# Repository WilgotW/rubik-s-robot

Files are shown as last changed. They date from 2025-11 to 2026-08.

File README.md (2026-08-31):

*Rubiks Cube Robot*

The purpose of this robot is to be able to scan, calculate solution and solve a rubiks cube. The robot has several different parts that interconnect: 
Mechanical (Robot Arm, color sensor, servos), 
Electronics (Custom made PCB with a STM32 chip), 
programming (Both computer program for solving the Rubiks cube as well as C programming for the STM32 IC)

This projects has divided all the files into sorted folders for each part of the robot told above. 

**Images**





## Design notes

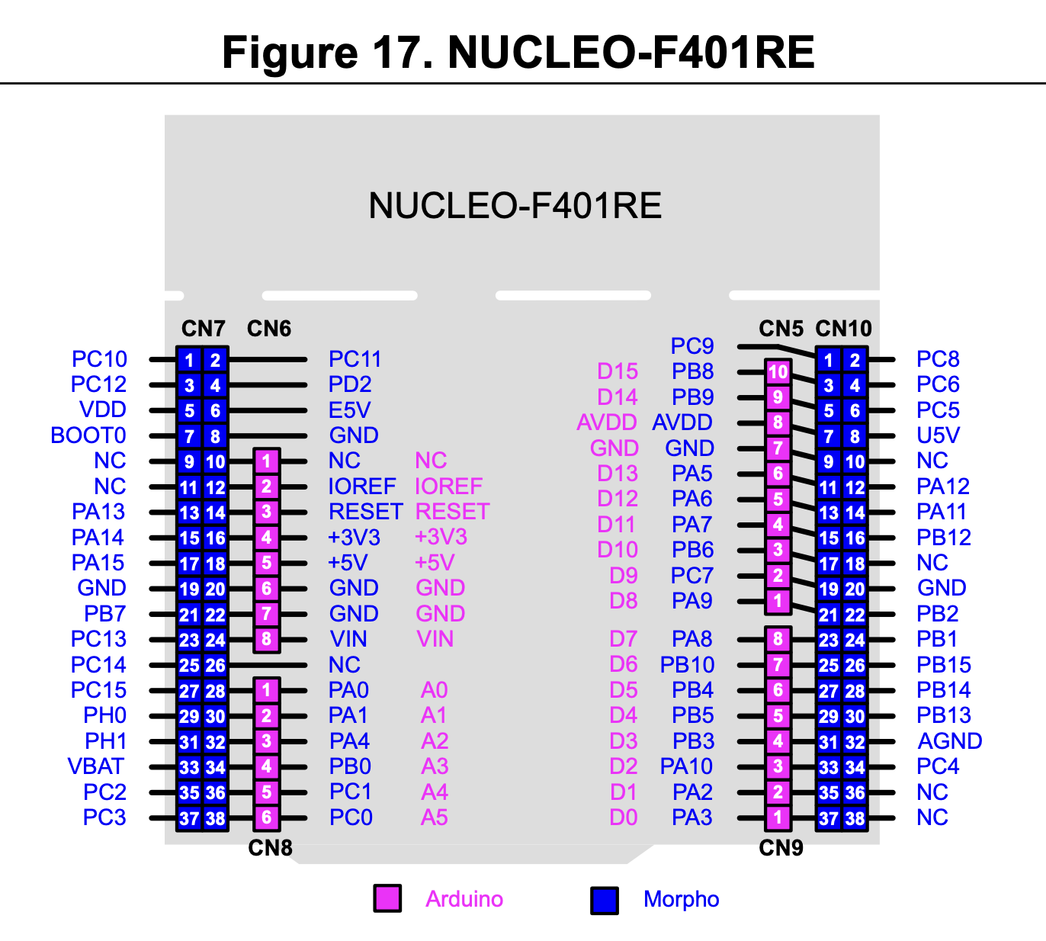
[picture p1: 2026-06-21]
rubiks-code/images/pin-layout.png

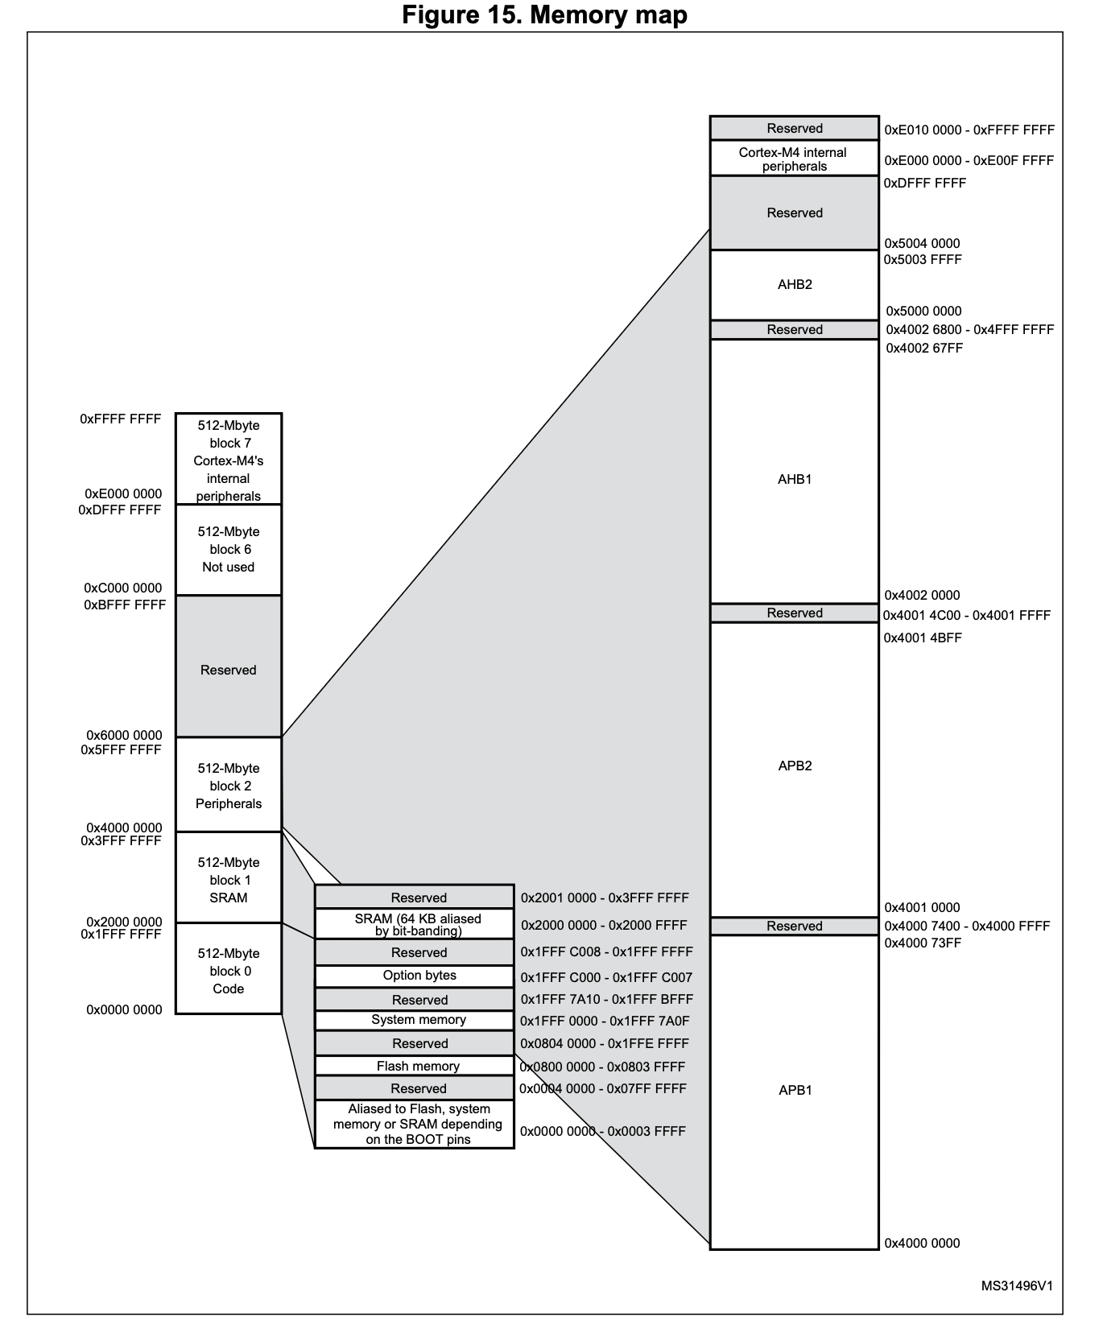
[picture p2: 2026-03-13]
rubiks-bare-metal/docs/memory_map.png

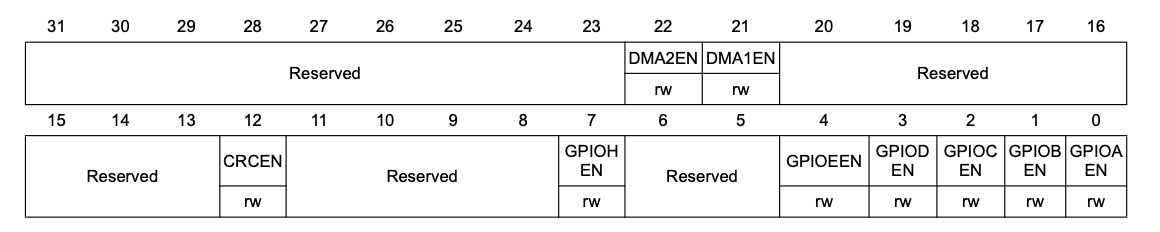
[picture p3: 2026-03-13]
rubiks-bare-metal/docs/RCC_AHB1ENR.png

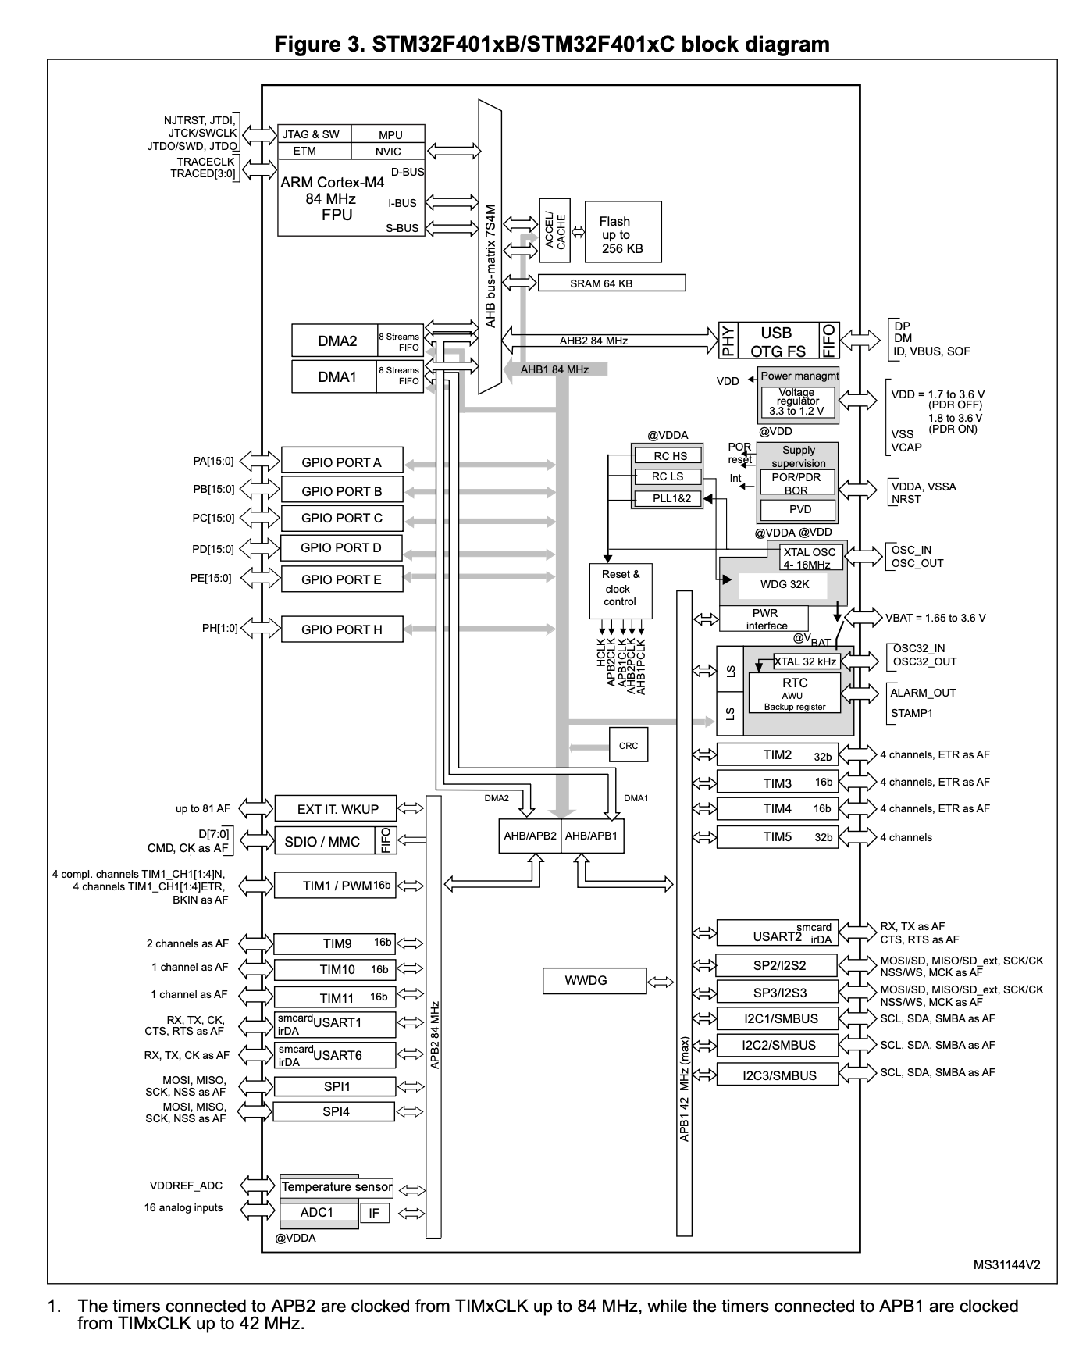
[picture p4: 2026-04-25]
rubiks-bare-metal/docs/Block_diagram.png

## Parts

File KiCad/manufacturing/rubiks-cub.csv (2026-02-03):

Reference | Qty | Value | DNP | Exclude from BOM | Exclude from Board | Footprint | Datasheet
A1,A2 | 2 | Pololu_Breakout_A4988 |  |  |  | Module:Pololu_Breakout-16_15.2x20.3mm | https://www.pololu.com/product/2980/pictures
C1,C2,C3,C4,C9,C16 | 6 | 100n |  |  |  | Capacitor_SMD:C_0402_1005Metric | ~
C5 | 1 | 10u |  |  |  | Capacitor_SMD:C_0603_1608Metric | ~
C6 | 1 | 10n |  |  |  | Capacitor_SMD:C_0402_1005Metric | ~
C7,C8 | 2 | 1u |  |  |  | Capacitor_SMD:C_0402_1005Metric | ~
C10,C11 | 2 | 10p |  |  |  | Capacitor_SMD:C_0402_1005Metric | ~
C12,C13 | 2 | 22u |  |  |  | Capacitor_SMD:C_0805_2012Metric | ~
C14 | 1 | 470u |  |  |  | Capacitor_THT:C_Radial_D8.0mm_H7.0mm_P3.50mm | ~
C15,C18 | 2 | 100u |  |  |  | Capacitor_THT:C_Radial_D8.0mm_H7.0mm_P3.50mm | ~
C17 | 1 | 4.7u |  |  |  | Capacitor_SMD:C_0603_1608Metric | ~
D1 | 1 | RED |  |  |  | LED_SMD:LED_0603_1608Metric | ~
D2 | 1 | SS34 |  |  |  | Diode_SMD:D_SMA | https://www.vishay.com/docs/88751/ss32.pdf
FB1 | 1 | 120R |  |  |  | Inductor_SMD:L_0603_1608Metric | ~
H1,H2,H3,H4 | 4 | MountingHole |  | Excluded from BOM |  | MountingHole:MountingHole_2.2mm_M2 | ~
J1 | 1 | USB_B_Mini |  |  |  | Connector_USB:USB_Mini-B_Wuerth_65100516121_Horizontal | ~
J2,J3,J4,J9,J16 | 5 | Conn_01x04_Pin |  |  |  | Connector_PinHeader_1.00mm:PinHeader_1x04_P1.00mm_Vertical | ~
J5 | 1 | Jack-DC |  |  |  | Connector_BarrelJack:BarrelJack_Horizontal | ~
J6,J13,J14,J15 | 4 | Conn_01x01_Pin |  |  |  | Connector_PinHeader_2.54mm:PinHeader_1x01_P2.54mm_Vertical | ~
J12 | 1 | Conn_01x03_Pin |  |  |  | Connector_PinHeader_1.00mm:PinHeader_1x03_P1.00mm_Vertical | ~
R1 | 1 | 10k |  |  |  | Resistor_SMD:R_0402_1005Metric | ~
R2,R3,R4,R6 | 4 | 1k5 |  |  |  | Resistor_SMD:R_0402_1005Metric | ~
SW1 | 1 | SW_SPDT |  |  |  | Button_Switch_SMD:SW_SPDT_PCM12 | ~
SW2 | 1 | SW_Push |  |  |  | Button_Switch_THT:SW_PUSH_6mm | ~
U1 | 1 | STM32F401RETx |  |  |  | Package_QFP:LQFP-64_10x10mm_P0.5mm | https://www.st.com/resource/en/datasheet/stm32f401re.pdf
U2 | 1 | AMS1117-3.3 |  |  |  | Package_TO_SOT_SMD:SOT-223-3_TabPin2 | http://www.advanced-monolithic.com/pdf/ds1117.pdf
Y1 | 1 | 16MHz |  |  |  | Crystal:Crystal_SMD_3225-4Pin_3.2x2.5mm | ~

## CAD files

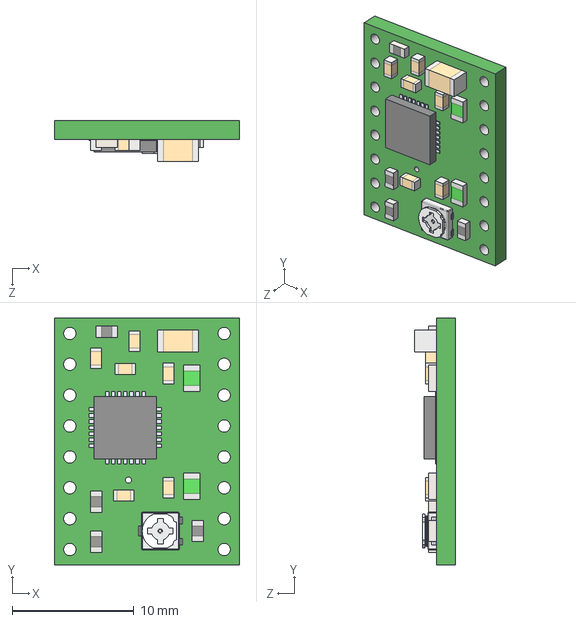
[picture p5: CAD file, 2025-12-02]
KiCad/models/a4988-stepper-motor-driver-carrier.step
15.2 x 20.3 x 3.37 mm

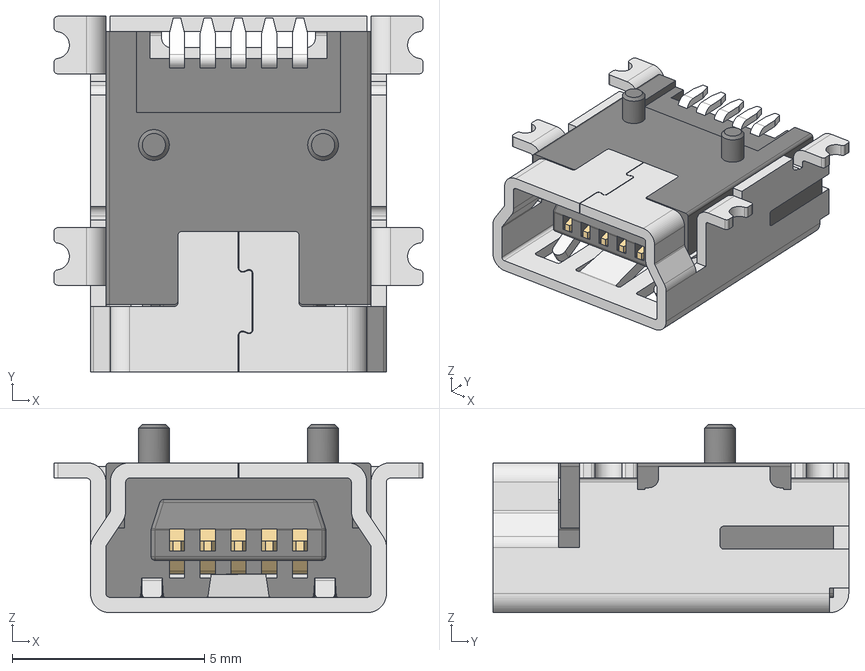
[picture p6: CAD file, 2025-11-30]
KiCad/models/65100516121+(rev1).stp
9.60 x 9.25 x 4.90 mm
Shielding
Insulator
Pin_1 x 5

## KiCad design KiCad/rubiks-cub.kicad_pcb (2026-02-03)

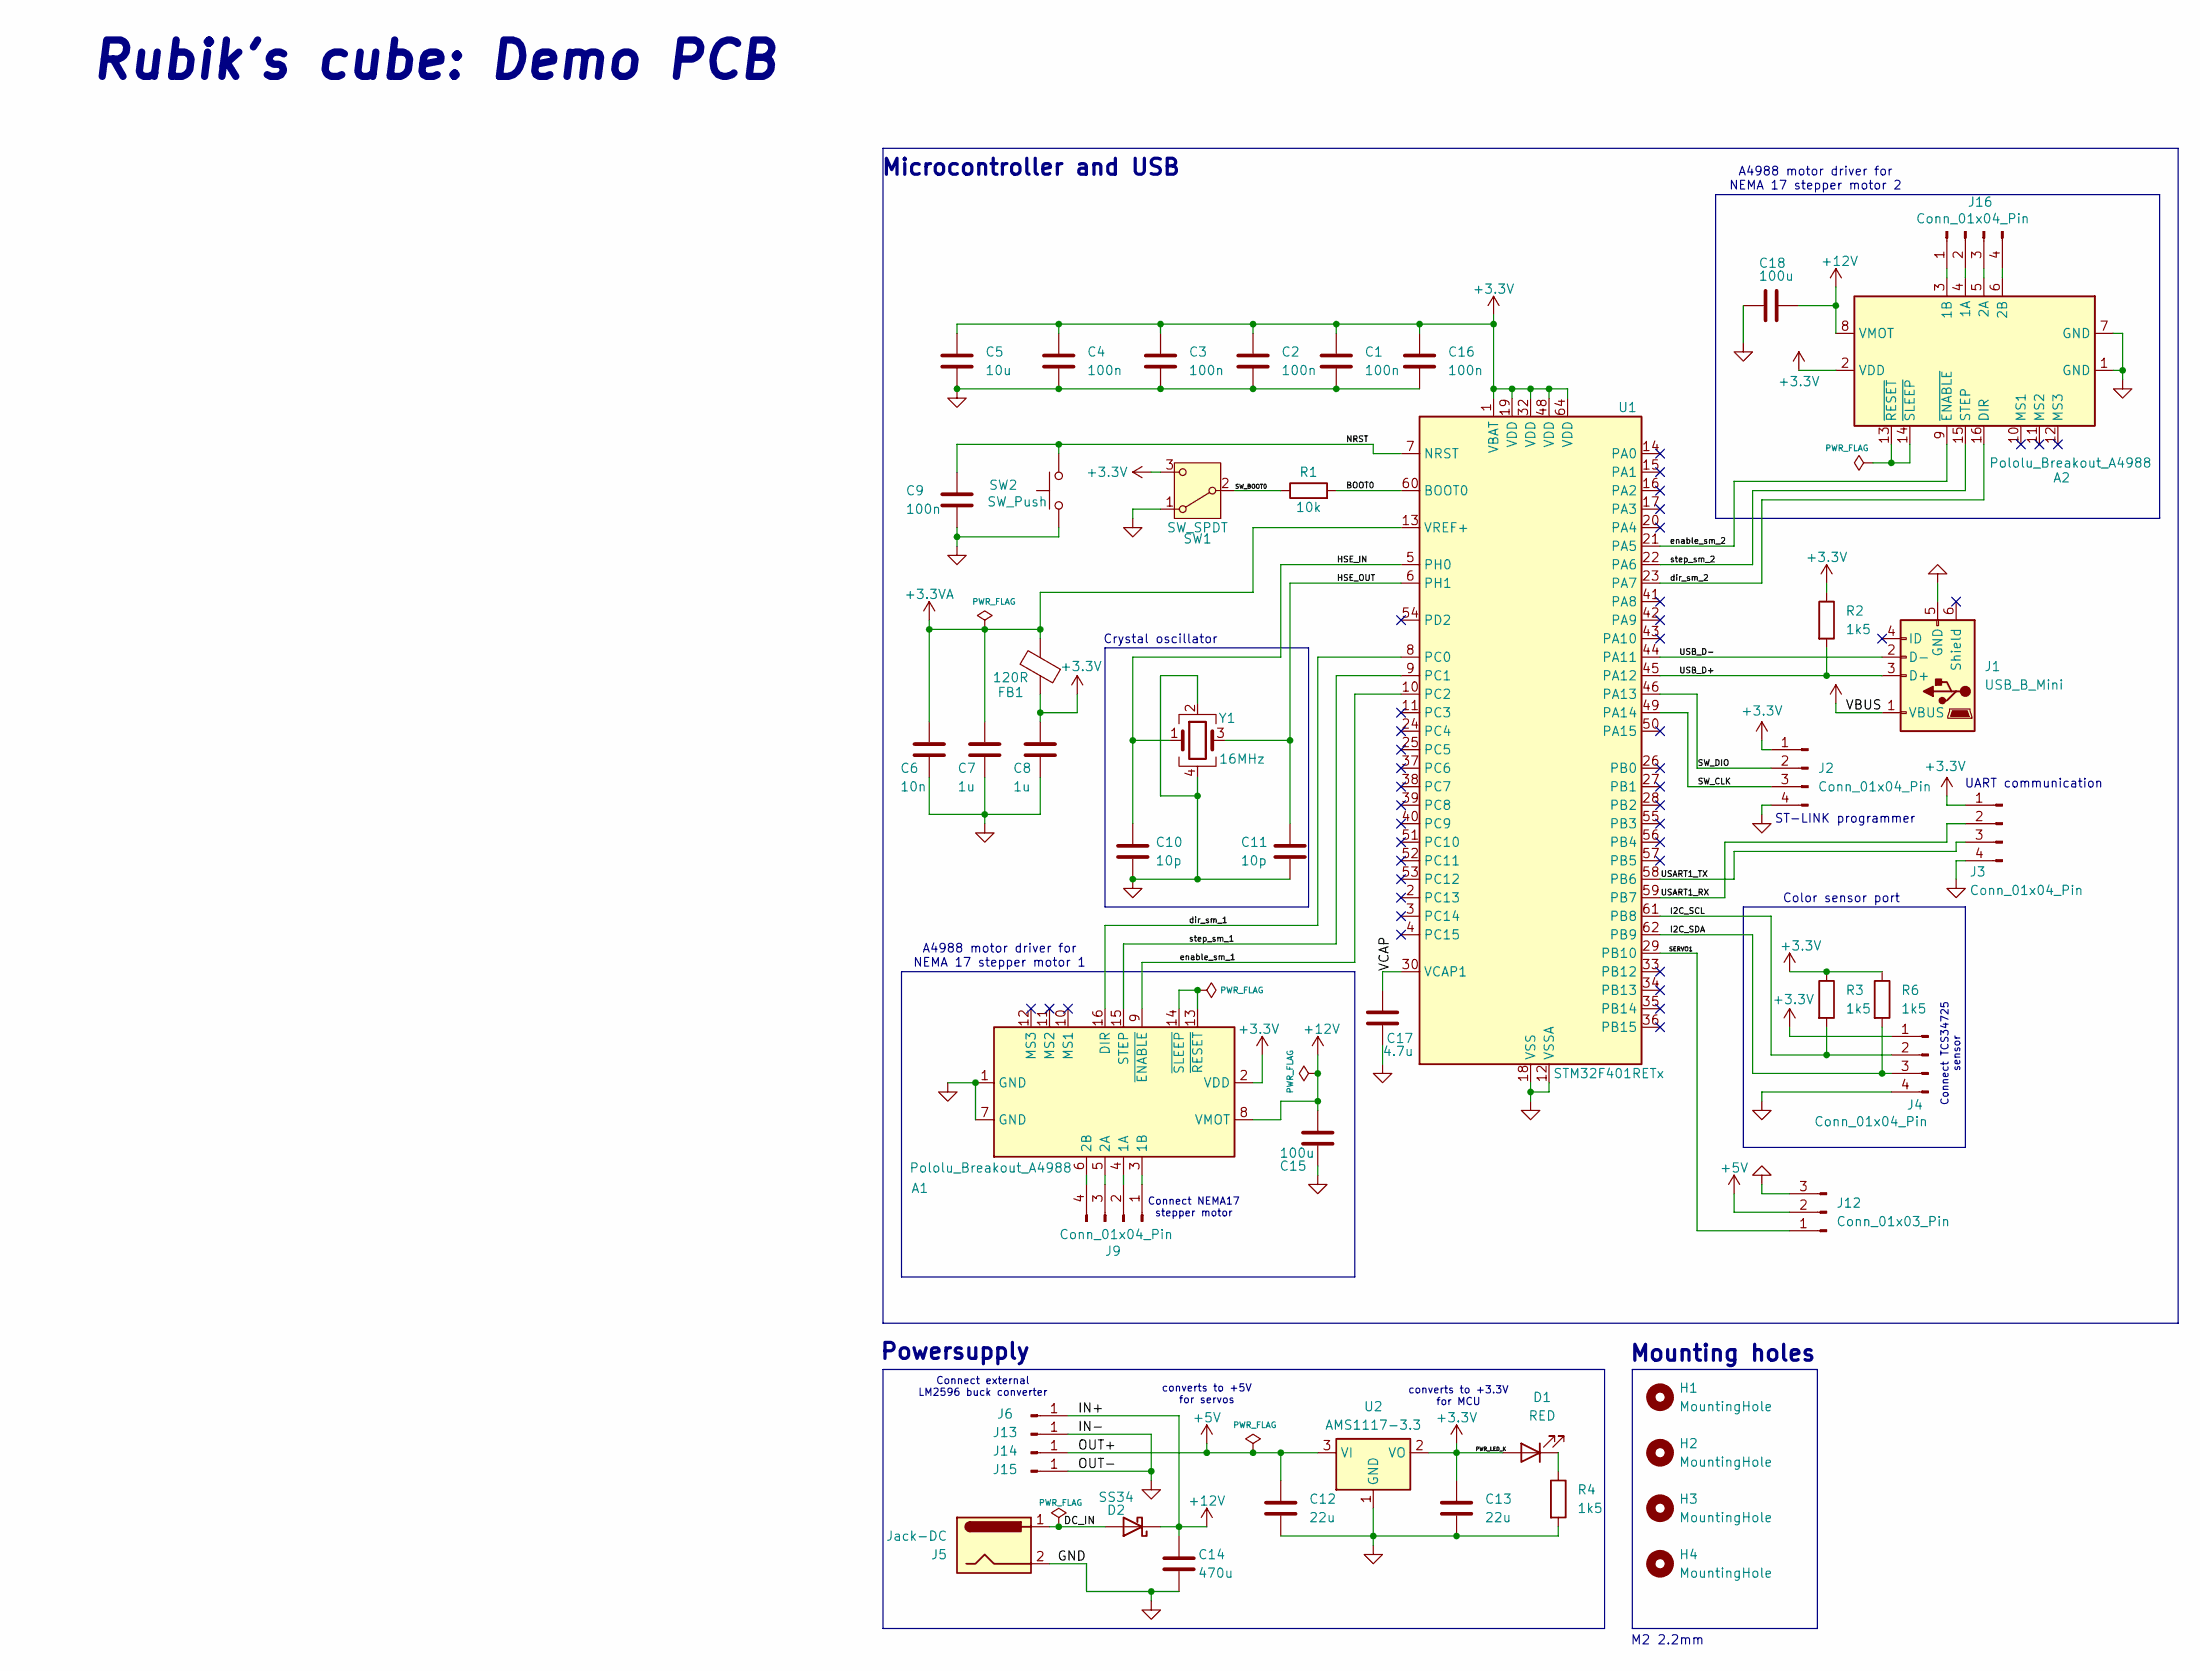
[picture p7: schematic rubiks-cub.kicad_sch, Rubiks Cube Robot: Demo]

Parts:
A1, A2: Pololu_Breakout_A4988; Pololu_Breakout-16_15.2x20.3mm
C1, C2, C3, C4, C9, C16: 100n; C_0402_1005Metric
C5: 10u; C_0603_1608Metric
C6: 10n; C_0402_1005Metric
C7, C8: 1u; C_0402_1005Metric
C10, C11: 10p; C_0402_1005Metric
C12, C13: 22u; C_0805_2012Metric
C14: 470u; C_Radial_D8.0mm_H7.0mm_P3.50mm
C15, C18: 100u; C_Radial_D8.0mm_H7.0mm_P3.50mm
C17: 4.7u; C_0603_1608Metric
D1: RED; LED_0603_1608Metric
D2: SS34; D_SMA
FB1: 120R; L_0603_1608Metric
H1, H2, H3, H4: MountingHole; MountingHole_2.2mm_M2
J1: USB_B_Mini; USB_Mini-B_Wuerth_65100516121_Horizontal
J2, J3, J4, J9, J16: Conn_01x04_Pin; PinHeader_1x04_P1.00mm_Vertical
J5: Jack-DC; BarrelJack_Horizontal
J6, J13, J14, J15: Conn_01x01_Pin; PinHeader_1x01_P2.54mm_Vertical
J12: Conn_01x03_Pin; PinHeader_1x03_P1.00mm_Vertical
R1: 10k; R_0402_1005Metric
R2, R3, R4, R6: 1k5; R_0402_1005Metric
SW1: SW_SPDT; SW_SPDT_PCM12
SW2: SW_Push; SW_PUSH_6mm
U1: STM32F401RETx; LQFP-64_10x10mm_P0.5mm
U2: AMS1117-3.3; SOT-223-3_TabPin2
Y1: 16MHz; Crystal_SMD_3225-4Pin_3.2x2.5mm

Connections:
+3.3V: A1.2 (VDD), A2.2 (VDD), C1.1, C2.1, C3.1, C4.1, C5.1, C8.1, C13.1, C16.1, D1.2 (A), FB1.1, J2.1, J3.1, J4.1, R2.1, R3.1, R6.1, SW1.3 (C), U1.1 (VBAT), U1.19 (VDD), U1.32 (VDD), U1.48 (VDD), U1.64 (VDD), U2.2 (VO)
+3.3VA: C6.1, C7.1, FB1.2, U1.13 (VREF+)
+5V: C12.1, J12.2, J14.1, U2.3 (VI)
+12V: A1.8 (VMOT), A2.8 (VMOT), C14.1, C15.2, C18.2, D2.1 (K), J6.1
/BOOT0: R1.2, U1.60 (BOOT0)
/DC_IN: D2.2 (A), J5.1
/HSE_IN: C10.1, U1.5 (PH0), Y1.1
/HSE_OUT: C11.1, U1.6 (PH1), Y1.3
/I2C_SCL: J4.2, R3.2, U1.61 (PB8)
/I2C_SDA: J4.3, R6.2, U1.62 (PB9)
/NRST: C9.1, SW2.2, U1.7 (NRST)
/SERVO1: J12.1, U1.29 (PB10)
/SW_BOOT0: R1.1, SW1.2 (B)
/SW_CLK: J2.3, U1.49 (PA14)
/SW_DIO: J2.2, U1.46 (PA13)
/USART1_RX: J3.2, U1.59 (PB7)
/USART1_TX: J3.3, U1.58 (PB6)
/USB_D+: J1.3 (D+), R2.2, U1.45 (PA12)
/USB_D-: J1.2 (D-), U1.44 (PA11)
/VCAP: C17.1, U1.30 (VCAP1)
/dir_sm_1: A1.16 (DIR), U1.8 (PC0)
/dir_sm_2: A2.16 (DIR), U1.23 (PA7)
/enable_sm_1: A1.9 (~ENABLE), U1.10 (PC2)
/enable_sm_2: A2.9 (~ENABLE), U1.21 (PA5)
/step_sm_1: A1.15 (STEP), U1.9 (PC1)
/step_sm_2: A2.15 (STEP), U1.22 (PA6)
GND: A1.1 (GND), A1.7 (GND), A2.1 (GND), A2.7 (GND), C1.2, C2.2, C3.2, C4.2, C5.2, C6.2, C7.2, C8.2, C9.2, C10.2, C11.2, C12.2, C13.2, C14.2, C15.1, C16.2, C17.2, C18.1, J1.5 (GND), J2.4, J3.4, J4.4, J5.2, J12.3, J13.1, J15.1, R4.2, SW1.1 (A), SW2.1, U1.12 (VSSA), U1.18 (VSS), U1.31 (VSS), U1.47 (VSS), U1.63 (VSS), U2.1 (GND), Y1.2, Y1.4
unnamed: A1.4 (1A), J9.2
unnamed: A1.3 (1B), J9.1
unnamed: A1.5 (2A), J9.3
unnamed: A1.6 (2B), J9.4
unnamed: A1.13 (~RESET), A1.14 (~SLEEP)
unnamed: A2.4 (1A), J16.2
unnamed: A2.3 (1B), J16.1
unnamed: A2.5 (2A), J16.3
unnamed: A2.6 (2B), J16.4
unnamed: A2.13 (~RESET), A2.14 (~SLEEP)
unnamed: D1.1 (K), R4.1
VBUS: J1.1 (VBUS)

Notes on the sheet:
Powersupply
Mounting holes
converts to +3.3V for MCU
Crystal oscillator
Connect TCS34725 sensor
ST-LINK programmer
Color sensor port
converts to +5V for servos
A4988 motor driver for NEMA 17 stepper motor 1
A4988 motor driver for NEMA 17 stepper motor 2
Connect external LM2596 buck converter
M2 2.2mm
UART communication
Rubik's cube: Demo PCB
Microcontroller and USB
Connect NEMA17 stepper motor

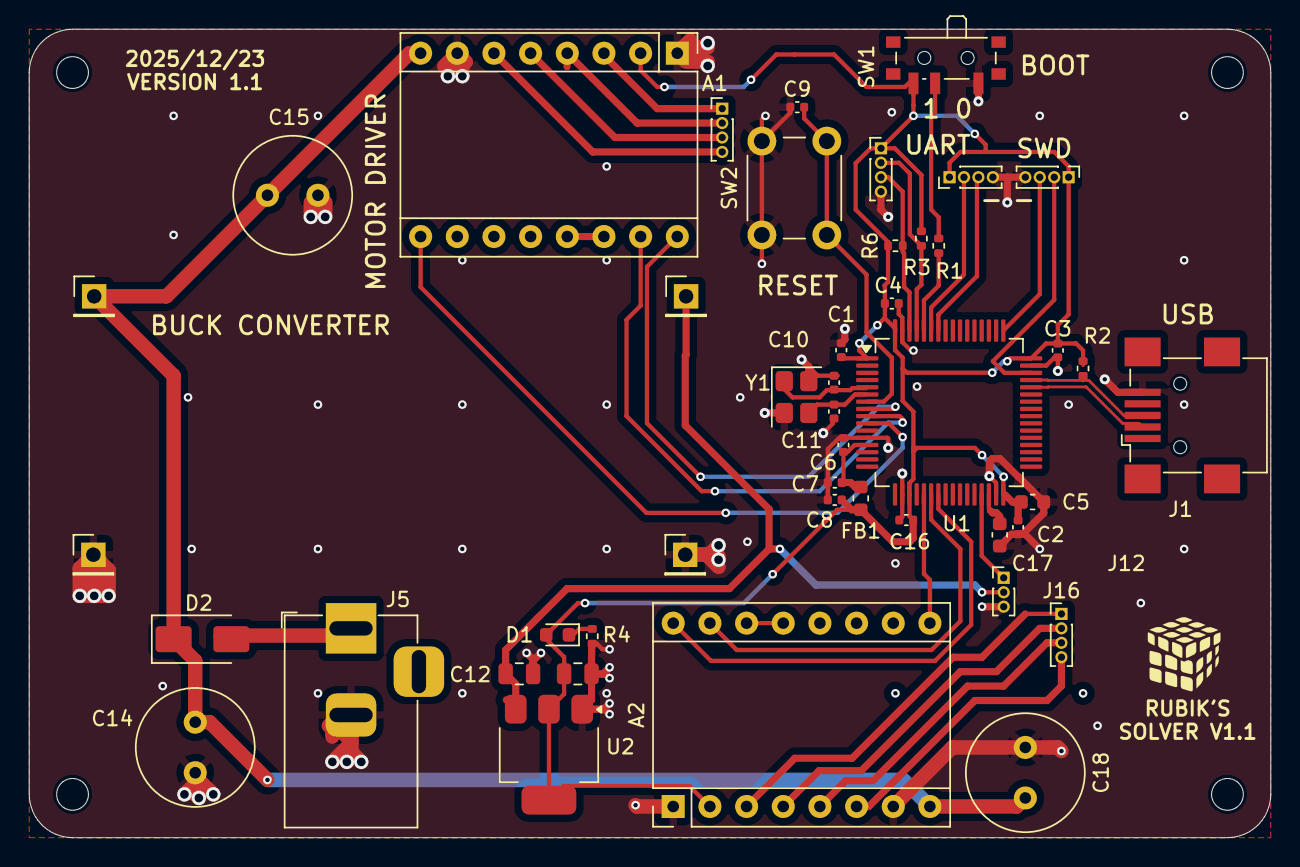
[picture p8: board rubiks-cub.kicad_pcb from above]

Board: 2 copper layers, 86.0 x 56.0 mm, 49 parts (0 on the bottom side), 38 nets.

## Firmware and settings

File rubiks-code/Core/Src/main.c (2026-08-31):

#include "main.h"
#include "stm32f401xe.h"
#include "uart.h"
#include "motor_driver.h"

void SystemClock_Config(void);
void Error_Handler(void);

void naive_delay(volatile uint32_t count) {
    while(count--) {
        __NOP(); 
    }
}

int main(void)
{
  HAL_Init();
  SystemClock_Config();

  //enable clock
  RCC->AHB1ENR |= ((1<<0) | (1<<1) | (1<<2));

  //custom drivers
  UART2_Init();
  Driver_Init();

  //SETUP USER BTN
  //user btn: PC13 - port C, pin 13
  //in the block diagram: Port C is connected to the AHB1 buss.
  GPIOC->MODER &= ~((1<<26) | (1<<27)); //set moder13 to input state (00)

  //SETUP USER LED
  //The user LED is connected is located at Port A, Pin 5. as seen in the user guide. 
  //in the datasheet, at the block diagram: we can see that PORT A is connected to the AHB1 bus
  //the base address for GPIO Port A is 0x4002 0000.
  GPIOA->MODER |= (1<<10);
  GPIOA->MODER &= ~(1<<11);


  while (1)
  {
    if ((USART2->SR & (1 << 5)) != 0){
      UART2_protocol();
    }
    // int btn_pressed = ((GPIOC->IDR & (1<<13)) == 0);

    // if(btn_pressed){
    //   GPIOA->ODR |= (1U << 5); 
    //   GPIOB->ODR |= (1U << 6); 
    //   naive_delay(3500);       

    //   GPIOA->ODR &= ~(1U << 5); 
    //   GPIOB->ODR &= ~(1U << 6);  
    //   naive_delay(3500);     

    // }else{
    //   GPIOA->ODR &= ~(1U << 5);
    //   GPIOB->ODR &= ~(1U << 6);
    // }

    
  }
}


//HAL code for configuring the clock signal
void SystemClock_Config(void)
{
  RCC_OscInitTypeDef RCC_OscInitStruct = {0};
  RCC_ClkInitTypeDef RCC_ClkInitStruct = {0};

  __HAL_RCC_PWR_CLK_ENABLE();
  __HAL_PWR_VOLTAGESCALING_CONFIG(PWR_REGULATOR_VOLTAGE_SCALE2);

  RCC_OscInitStruct.OscillatorType = RCC_OSCILLATORTYPE_HSI;
  RCC_OscInitStruct.HSIState = RCC_HSI_ON;
  RCC_OscInitStruct.HSICalibrationValue = RCC_HSICALIBRATION_DEFAULT;
  RCC_OscInitStruct.PLL.PLLState = RCC_PLL_ON;
  RCC_OscInitStruct.PLL.PLLSource = RCC_PLLSOURCE_HSI;
  RCC_OscInitStruct.PLL.PLLM = 16;
  RCC_OscInitStruct.PLL.PLLN = 336;
  RCC_OscInitStruct.PLL.PLLP = RCC_PLLP_DIV4;
  RCC_OscInitStruct.PLL.PLLQ = 7;
  
  if (HAL_RCC_OscConfig(&RCC_OscInitStruct) != HAL_OK)
  {
    Error_Handler();
  }

  RCC_ClkInitStruct.ClockType = RCC_CLOCKTYPE_HCLK | RCC_CLOCKTYPE_SYSCLK | 
                                RCC_CLOCKTYPE_PCLK1 | RCC_CLOCKTYPE_PCLK2;
  RCC_ClkInitStruct.SYSCLKSource = RCC_SYSCLKSOURCE_PLLCLK;
  RCC_ClkInitStruct.AHBCLKDivider = RCC_SYSCLK_DIV1;
  RCC_ClkInitStruct.APB1CLKDivider = RCC_HCLK_DIV2;
  RCC_ClkInitStruct.APB2CLKDivider = RCC_HCLK_DIV1;

  if (HAL_RCC_ClockConfig(&RCC_ClkInitStruct, FLASH_LATENCY_2) != HAL_OK)
  {
    Error_Handler();
  }
}

void Error_Handler(void)
{
  __disable_irq();
  while (1)
  {
  }
}

#ifdef  USE_FULL_ASSERT
void assert_failed(uint8_t *file, uint32_t line)
{
}
#endif

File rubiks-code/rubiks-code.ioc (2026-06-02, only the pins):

Mcu.UserName=STM32F401RETx
PA13.Signal=SYS_JTMS-SWDIO
PA14.Signal=SYS_JTCK-SWCLK

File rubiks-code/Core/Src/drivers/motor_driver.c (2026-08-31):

#include "stm32f401xe.h"
#include <stdint.h>

//NOTE: Update this to Hardware timers instead
void step_delay(volatile uint32_t count) {
    while(count--) {
        __NOP(); 
    }
}

void execute_motor_move(uint8_t move, uint8_t motor){
    
    //ensure enable pin is LOW
    //GPIOA->ODR &= ~(1U << 7);
    
    step_delay(5000);

    //set direction. R = clockwise, r = counter-clockwise
    // if(move == 'R'){
    //     GPIOA->ODR |= (1U << 6); //HIGH
    // }else if (move = 'r'){
    //     GPIOA->ODR &= ~(1U << 6); //LOW
    // }
    
    //Generate steps
    int steps_90_deg = 400;
    for (int i = 0; i < steps_90_deg; i++){
        if(motor == 0){
            GPIOA->ODR |= (1U<< 5);
            step_delay(3000);

            GPIOA->ODR &= ~(1U << 5);
            step_delay(3000);
        }else if (motor == 1){
            GPIOB->ODR |= (1U << 6);
            step_delay(3000);

            GPIOB->ODR &= ~(1U << 6);
            step_delay(3000);
        }
    }

    // if(motor == 1){
    //     for (int y = 0; y < 50; y++){
    //         GPIOB->ODR |= (1U << 6);
    //         step_delay(3000);

    //         GPIOB->ODR &= ~(1U << 6);
    //         step_delay(3000);
    //     }
    // }
}



void Driver_Init(void){
    //driver 1
    //clear bits for PA5 (STEP), PA6 (DIR), PA7 (EN)
    GPIOA->MODER &= ~((3U << (5 * 2)) | (3U << (6 * 2)) | (3U << (7 * 2))); 
    //Set to output
    GPIOA->MODER |=  ((1U << (5 * 2)) | (1U << (6 * 2)) | (1U << (7 * 2))); 

    //driver 2
    //Clear bits 
    GPIOB->MODER &= ~((3U << (6 * 2)) | (3U << (7 * 2)) | (3U << (8 * 2)));
    //Set to output
    GPIOB->MODER |=  ((1U << (6 * 2)) | (1U << (7 * 2)) | (1U << (8 * 2)));
    
    //Driver 1
    GPIOA->ODR &= ~(1U << 7);  //Pull EN (PA7) LOW
    GPIOA->ODR |=  (1U << 6);  //Set DIR (PA6) HIGH 

    //driver 2 
    GPIOB->ODR &= ~(1U << 8);  //Pull (PB8) LOW
    GPIOB->ODR |=  (1U << 7);  //Set DIR (PB7) HIGH 
}

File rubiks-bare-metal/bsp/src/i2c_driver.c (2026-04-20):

//I2C drivers for color sensor
//How I2C works:
//The system consists of a master and slaves that is connected to each other via two common lines: SDA and SCL
//SDA is the data line while SCL is the common clock line that all devices will use to be synchronized.  
//Both the SDA and SCL line are connected to a pull up resistor to reduce noise in the data and clock. This means that communications occures by pulling the lines from HIGH to LOW

//1. The master starts by pulling the data line to LOW, this signals to all slaves that a message is comming. 
//2. The master then sends a 8 bit address that's owned by one of the slaves. In the message is an additional read/write bit which tells the correct reciever if it should recieve or send data in the upcoming step
//3. The address reaches all the slaves: The slaves compare the address to it's internal address and checks if there's a match. If not, the internal state machine goes into an ignore mode, which means it wont listen to upcoming data on the SDA line. If there's an match, the correct slave responds to the master by sending an ACK (acknowledgement) to signal that it recieved the signal.
// If the master doesnt recieve an ACK after a timer runs out, it knows that something went wrong, and tries again. 
//4. Now that the master has recieved the ACK, theres an active path between the right slave and the master. Data can now be sent
//5. depending on the write/read bit that was sent on step 2, the slave or the masters sends data. After each packet of data, the reciever needs to send an ACK to confirm that it got everything right.

//To implement this driver, we have to control several registers to make this work:
//Control register: I2C_CR1 and I2C_CR2. These registers are configured to send start and stop condition of the communication. Aswell as enabling ACKs. 
//Data register: I2C_DR is the data register. Data stored here is automaticaly sent out on the SDA line.
//Status registers: I2C_SR1 and I2C_SR2. these registers are used to constantly check that communication is going as planned. All the bits in these registers tells what is going on:
// -SB bit: did start condition finish?
// -ADDR bit: Did sensor ACK its address?
// -TXE bit: is SDR empty so new data can be sent?

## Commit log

2025-11-27 power regulator
2025-11-27 demo pcb schematic done
    [rubiks-cub.kicad_sch]
2025-11-29 added extra components
    [rubiks-cub.kicad_sch]
2025-11-29 schematic done
2025-12-02 pcb design
    [rubiks-cub.kicad_pcb, rubiks-cub.kicad_sch]
2025-12-22 pcb progress
    [rubiks-cub.kicad_pcb]
2026-06-09 UART working
2026-06-30 driver setup
